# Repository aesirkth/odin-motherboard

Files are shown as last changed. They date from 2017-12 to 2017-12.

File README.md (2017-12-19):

# ÆSIR - Odin Motherboard
Odin Motherboard KiCad Design Files

This repository contains the motherboard KiCad design files for the ÆSIR Odin hybrid rocket.
Its main purpose is to house the on-board computer, a Teensy v3.6, and the breakouts to all external components in the rocket. These include: GPS, Go Pro, telemetry, servo, video/camera transmission, accelerometer, umbilical cord, and a safety pin. Use the reference_breakout.txt file to see where each output goes to. 

aesir.lib contains the schematic symbols for the BMP180, MPU-9250, and the motherboard plate (68 mm diameter)

AESIR.pretty contains the footprints for the BMP180, MPU-9250, and the motherboard plate (68 mm diameter).

The Teensy v3.6 KiCad component is required.
Download the schematic symbols and footprints from: 
https://github.com/XenGi/teensy_library

Watch our progress at http://aesir.se/!

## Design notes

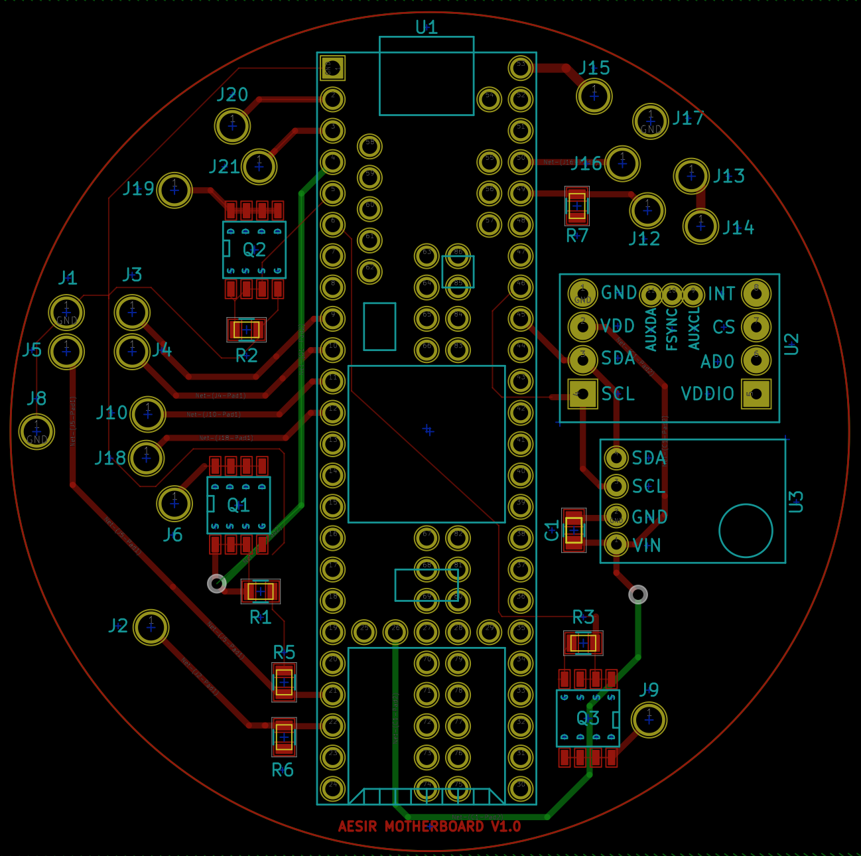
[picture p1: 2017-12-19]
AESIR_MB_FOOTPRINT.png

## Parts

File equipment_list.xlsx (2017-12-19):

No. | Description | Code | Web-link | Pcs. | Price/pcs. | VAT (if) | Price (SEK) | Description in OF | Notes
1 | RFD868+ Modem Bundle | BUNDLE-RFD868+ | http://store.rfdesign.com.au/rfd868-modem-bundle/ | 1 | 1550 | 387.5 | 1937.5 | Telemetry unit
2 | RF Extension Cable - RPSMA(M)-RPSMA(F) 15cm | CABLE-RPSMA-EXT-15cm | http://store.rfdesign.com.au/rf-extension-cable-rpsma-m-rpsma-f-15cm/ | 2 | 45 | 22.5 | 112.5
3 | RF Extension Cable - RPSMA(M)-RPSMA(F) 50cm | CABLE-RPSMA-EXT-50cm | http://store.rfdesign.com.au/rf-extension-cable-rpsma-m-rpsma-f-50cm/ | 2 | 40 | 20 | 100
4 | Transport for Modems & Accs. |  |  | 1 | 200 | 50 | 350
5 | RMRC - 1.3GHz 1000mW Transmitter | V2-1000MW1300MHZTX-INTL | https://www.readymaderc.com/store/index.php?main_page=product_info&cPath=11_30_38&products_id=921 | 1 | 800 | 200 | 1000 | Video unit
6 | RMRC - 900MHz-1.3Ghz Receiver w/1258 | V3-900MHZ-1.3GHZRX | https://www.readymaderc.com/store/index.php?main_page=product_info&cPath=11_34_44&products_id=912 | 1 | 490 | 122.5 | 612.5
7 | VAS - 1.3GHz BiQuad Antenna | BQ-1280 | https://www.readymaderc.com/store/index.php?main_page=product_info&cPath=11_45_52_99&products_id=378 | 1 | 625 | 156.25 | 781.25
8 | 30cm (1ft) SMA Female to SMA Male RG316 Extension | SMAMF30CM | https://www.readymaderc.com/store/index.php?main_page=product_info&cPath=11_45_58&products_id=250 | 1 | 70 | 17.5 | 87.5
9 | 15cm SMA Female to SMA Male RG316 Extension | SMAMF15CM | https://www.readymaderc.com/store/index.php?main_page=product_info&cPath=11_45_58&products_id=3726 | 2 | 35 | 17.5 | 87.5
10 | Shipping for Video items |  |  | 1 | 200 | 50 | 250
11 | Data Acquisition | DI-710-UL | https://www.dataq.com/products/di-710/di-710-ul.html | 1 | 4420 | 1105 | 5525 | DAQ
12 | Shipping for DAQ |  |  | 1 | 780 | 195 | 975
12 | GoPro Hero4 Black |  | http://www.elgiganten.se/product/foto-video/actionkamera/GOPROHER4BLK/gopro-hero-4-black-adventure-edition-actionkamera | 1 | 4000 | 0 | 4000 |  | need 4 black because it's the last one that has the plug to command the recording
 | Funding from the Opportunities Grant = |  | 16100 |  |  | Total | 15818.75
 |  |  |  |  |  | Total telem. | 2500
 | Contains equipment for both motherboard and daugterboard |  |  |  |  | Total video | 2818.75
 |  |  |  |  |  | Remaining | 281.25
 | Others
13 | Resistors |  | http://se.farnell.com/yageo-phycomp/rc0805fr-071kl/motst-tjockfilm-1k-1-0-125w-0805/dp/9237496 | 10 | 0.12 |  | 1.2 | Farnell
14 | N type mosfet |  | http://se.farnell.com/vishay/si4840bdy-t1-e3/mosfet-n-so-8/dp/1684057 | 8 | 11.06 |  | 88.48
15 | Diodes |  | http://se.farnell.com/bourns/cd214b-r3600/diode-chip-600v-3a-do-214aa/dp/2311234 | 6 | 3.72 |  | 22.32
16 | Supercap |  | http://se.farnell.com/vishay/mal219613473e3/cap-double-47000uf-6-3v-rad/dp/1695337 | 1 | 53 |  | 53
17 | Shipping for Farnell |  |  | 1 | 200 |  | 200
18 | Step down reg |  | https://www.pololu.com/product/2852 | 3 | 105 | 78.75 | 393.75 | Pololu
19 | Step up reg |  | https://www.pololu.com/product/2117 | 2 | 35 | 17.5 | 87.5
20 | Arduino mini pro |  | https://www.sparkfun.com/products/11113 | 3 | 89 | 66.75 | 333.75 | Sparkfun
21 | Arduino Stackable Header Kit |  | https://www.sparkfun.com/products/11417 | 3 | 14 | 10.5 | 52.5
22 | SparkFun microSD Breakout board |  | https://www.sparkfun.com/products/13743 | 1 | 45 | 11.25 | 56.25
23 | miscellaneous |  |  | 0 |  | 0 | 200
24 | SparkFun IMU Breakout - MPU-9250 |  | https://www.sparkfun.com/products/13762 | 1 | 132 | 33 | 165
25 | SparkFun Logic Level Converter |  | https://www.sparkfun.com/products/12009 | 2 | 27 | 13.5 | 67.5
26 | Micro SD card for GoPro |  |  | 1 |  |  |  |  | 32gb - class enough for 2.7k 60fps
27 | Micro SD card for data storage |  |  | 1 |  |  |  |  | not bigger than 4gb
26 | Force cell sensor | MSP6954-ND | http://www.digikey.com/products/en/sensors-transducers/force-sensors/531?k=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 | 1 | 1062 | 265.5 | 1327.5 | Digikey
27 | Shippind for force cell |  |  | 1 | 70 | 17.5 | 87.5
 |  |  |  |  |  | Total | 3136.25

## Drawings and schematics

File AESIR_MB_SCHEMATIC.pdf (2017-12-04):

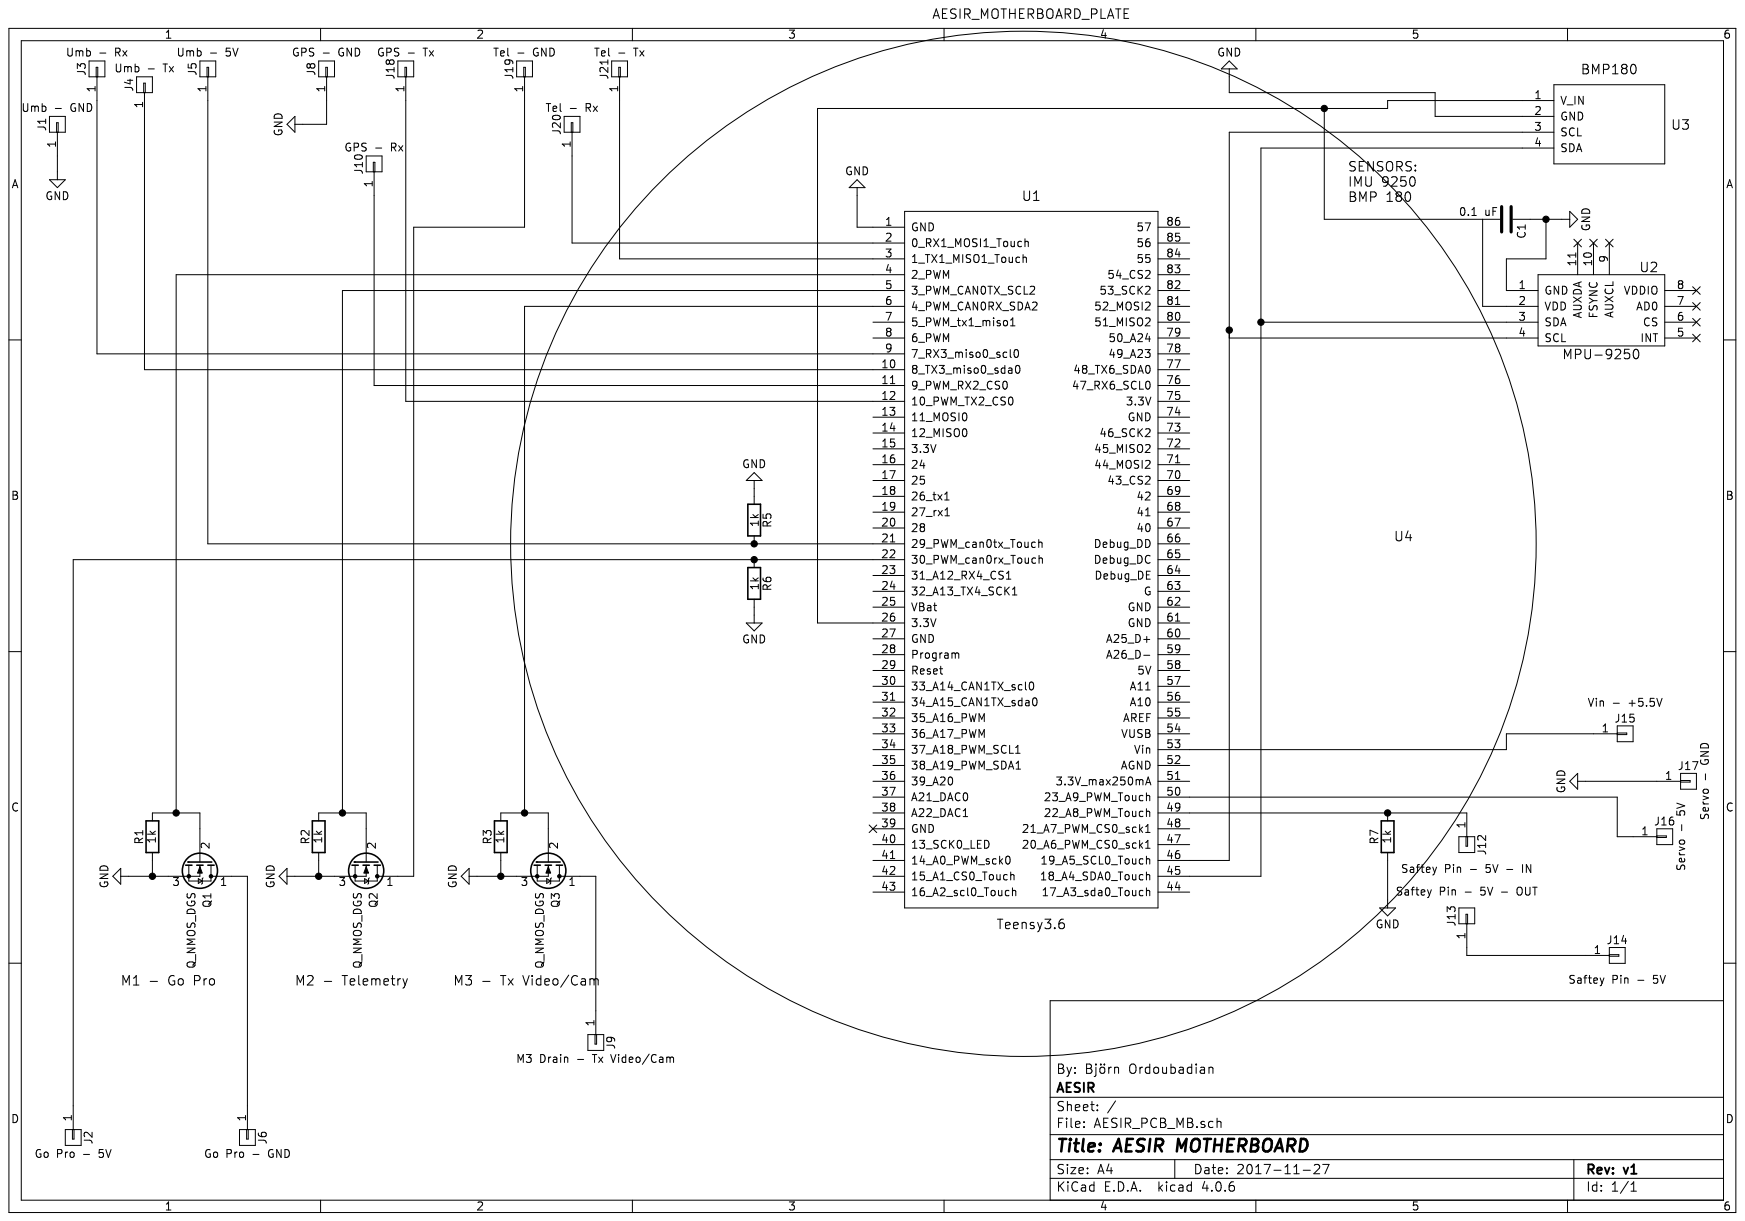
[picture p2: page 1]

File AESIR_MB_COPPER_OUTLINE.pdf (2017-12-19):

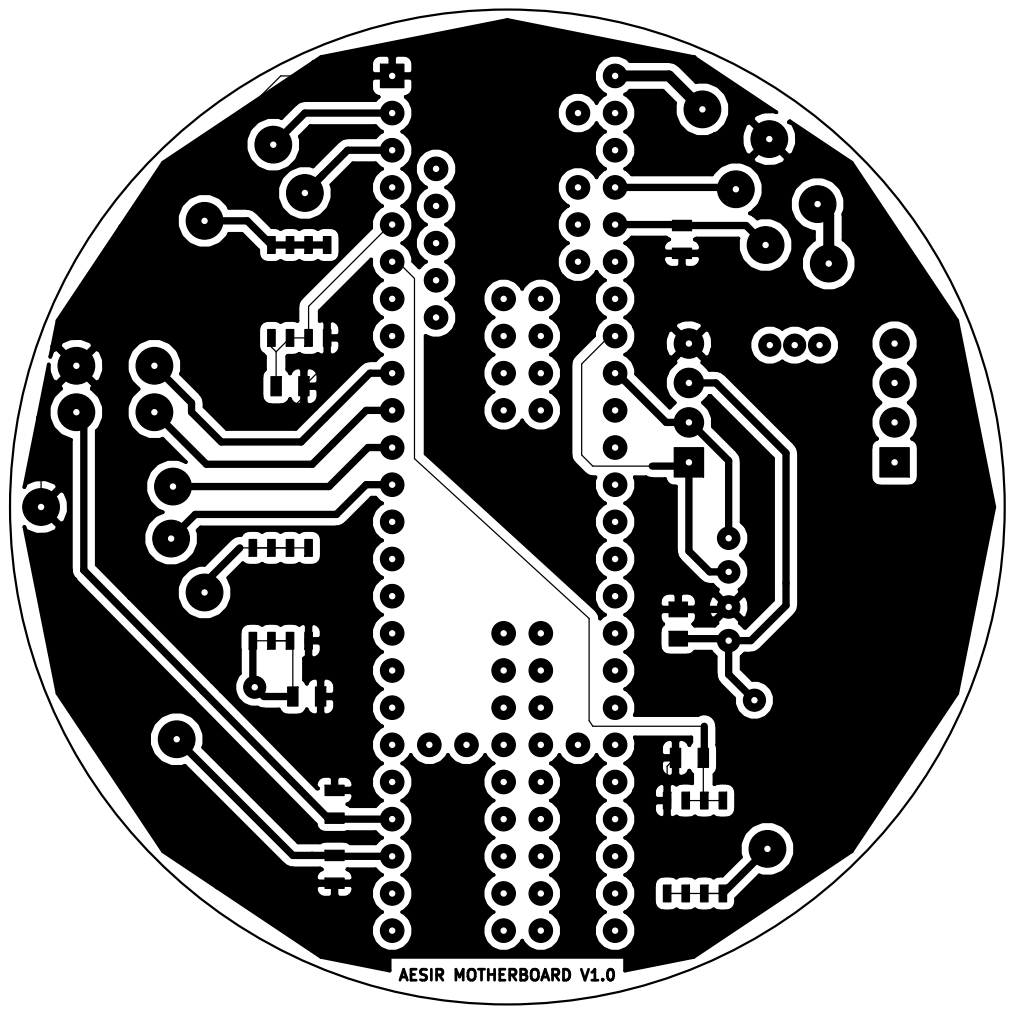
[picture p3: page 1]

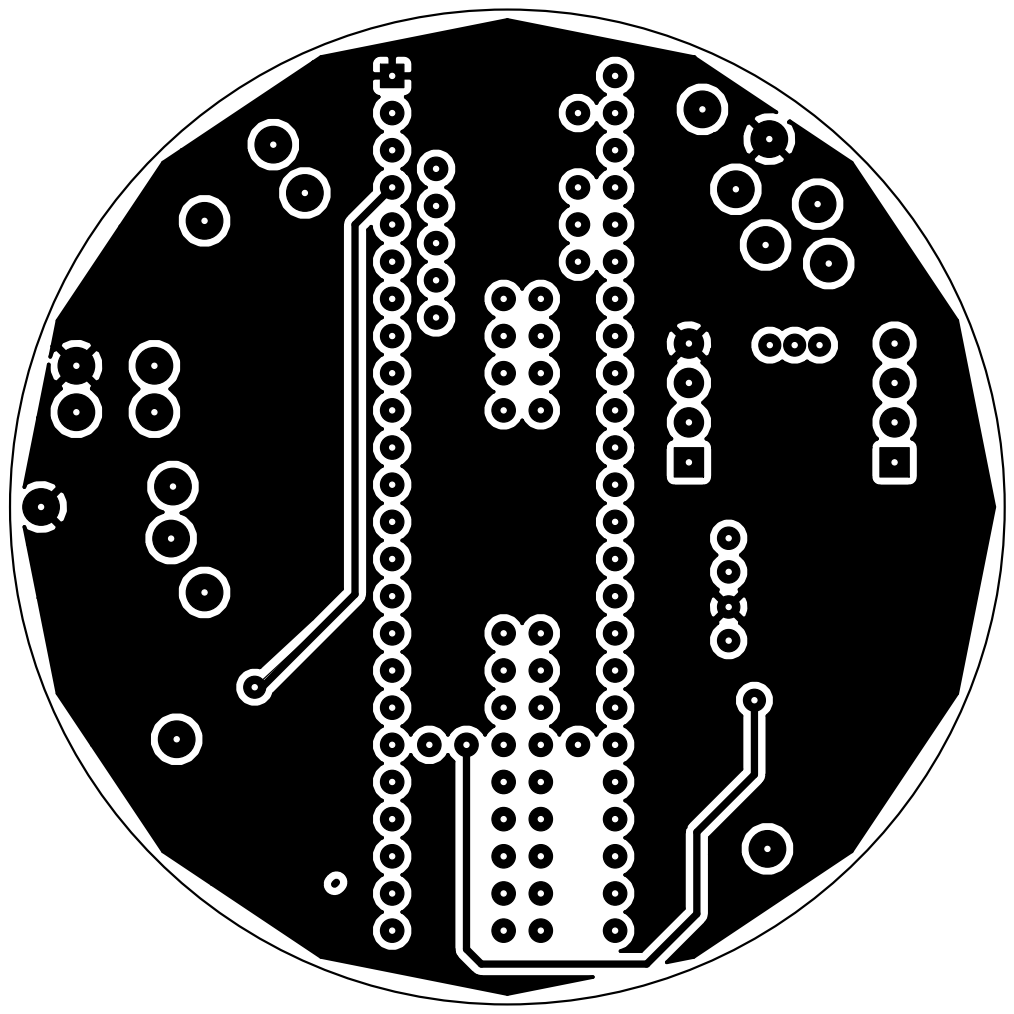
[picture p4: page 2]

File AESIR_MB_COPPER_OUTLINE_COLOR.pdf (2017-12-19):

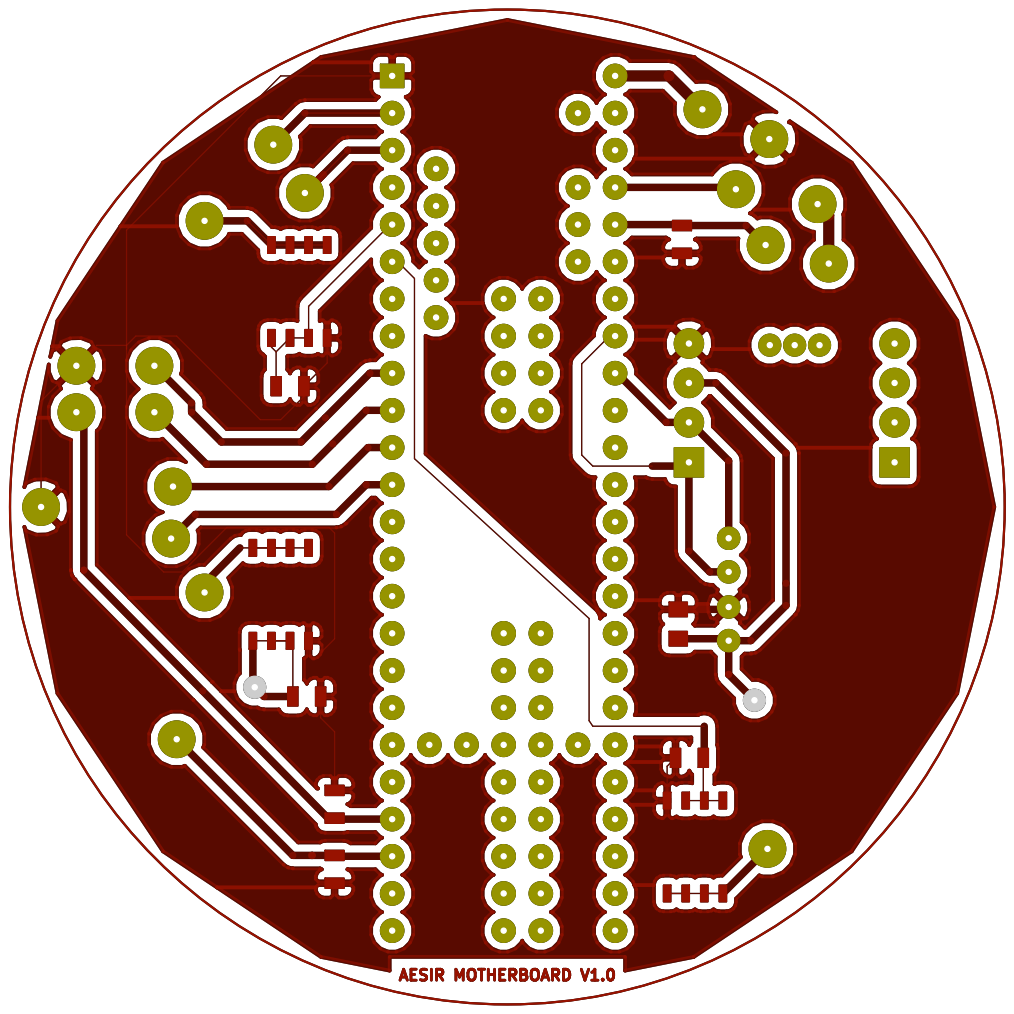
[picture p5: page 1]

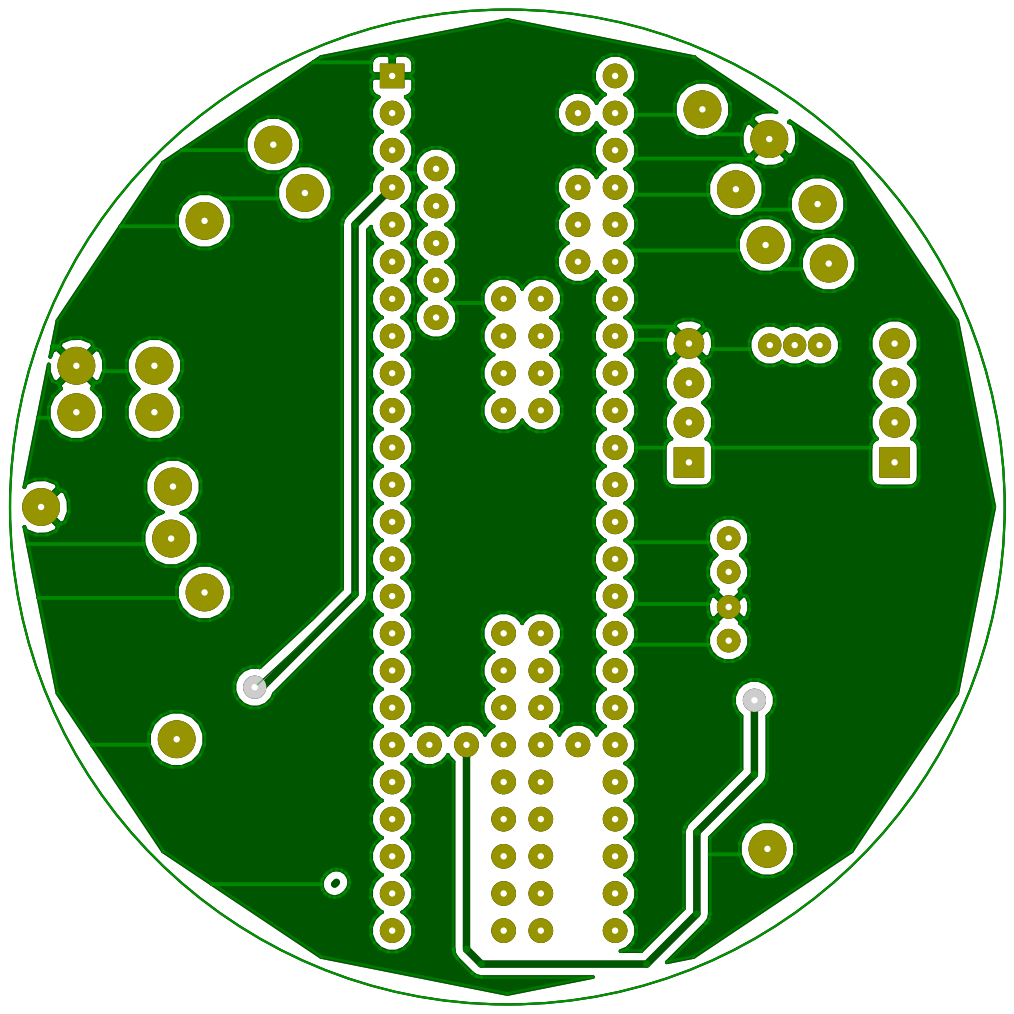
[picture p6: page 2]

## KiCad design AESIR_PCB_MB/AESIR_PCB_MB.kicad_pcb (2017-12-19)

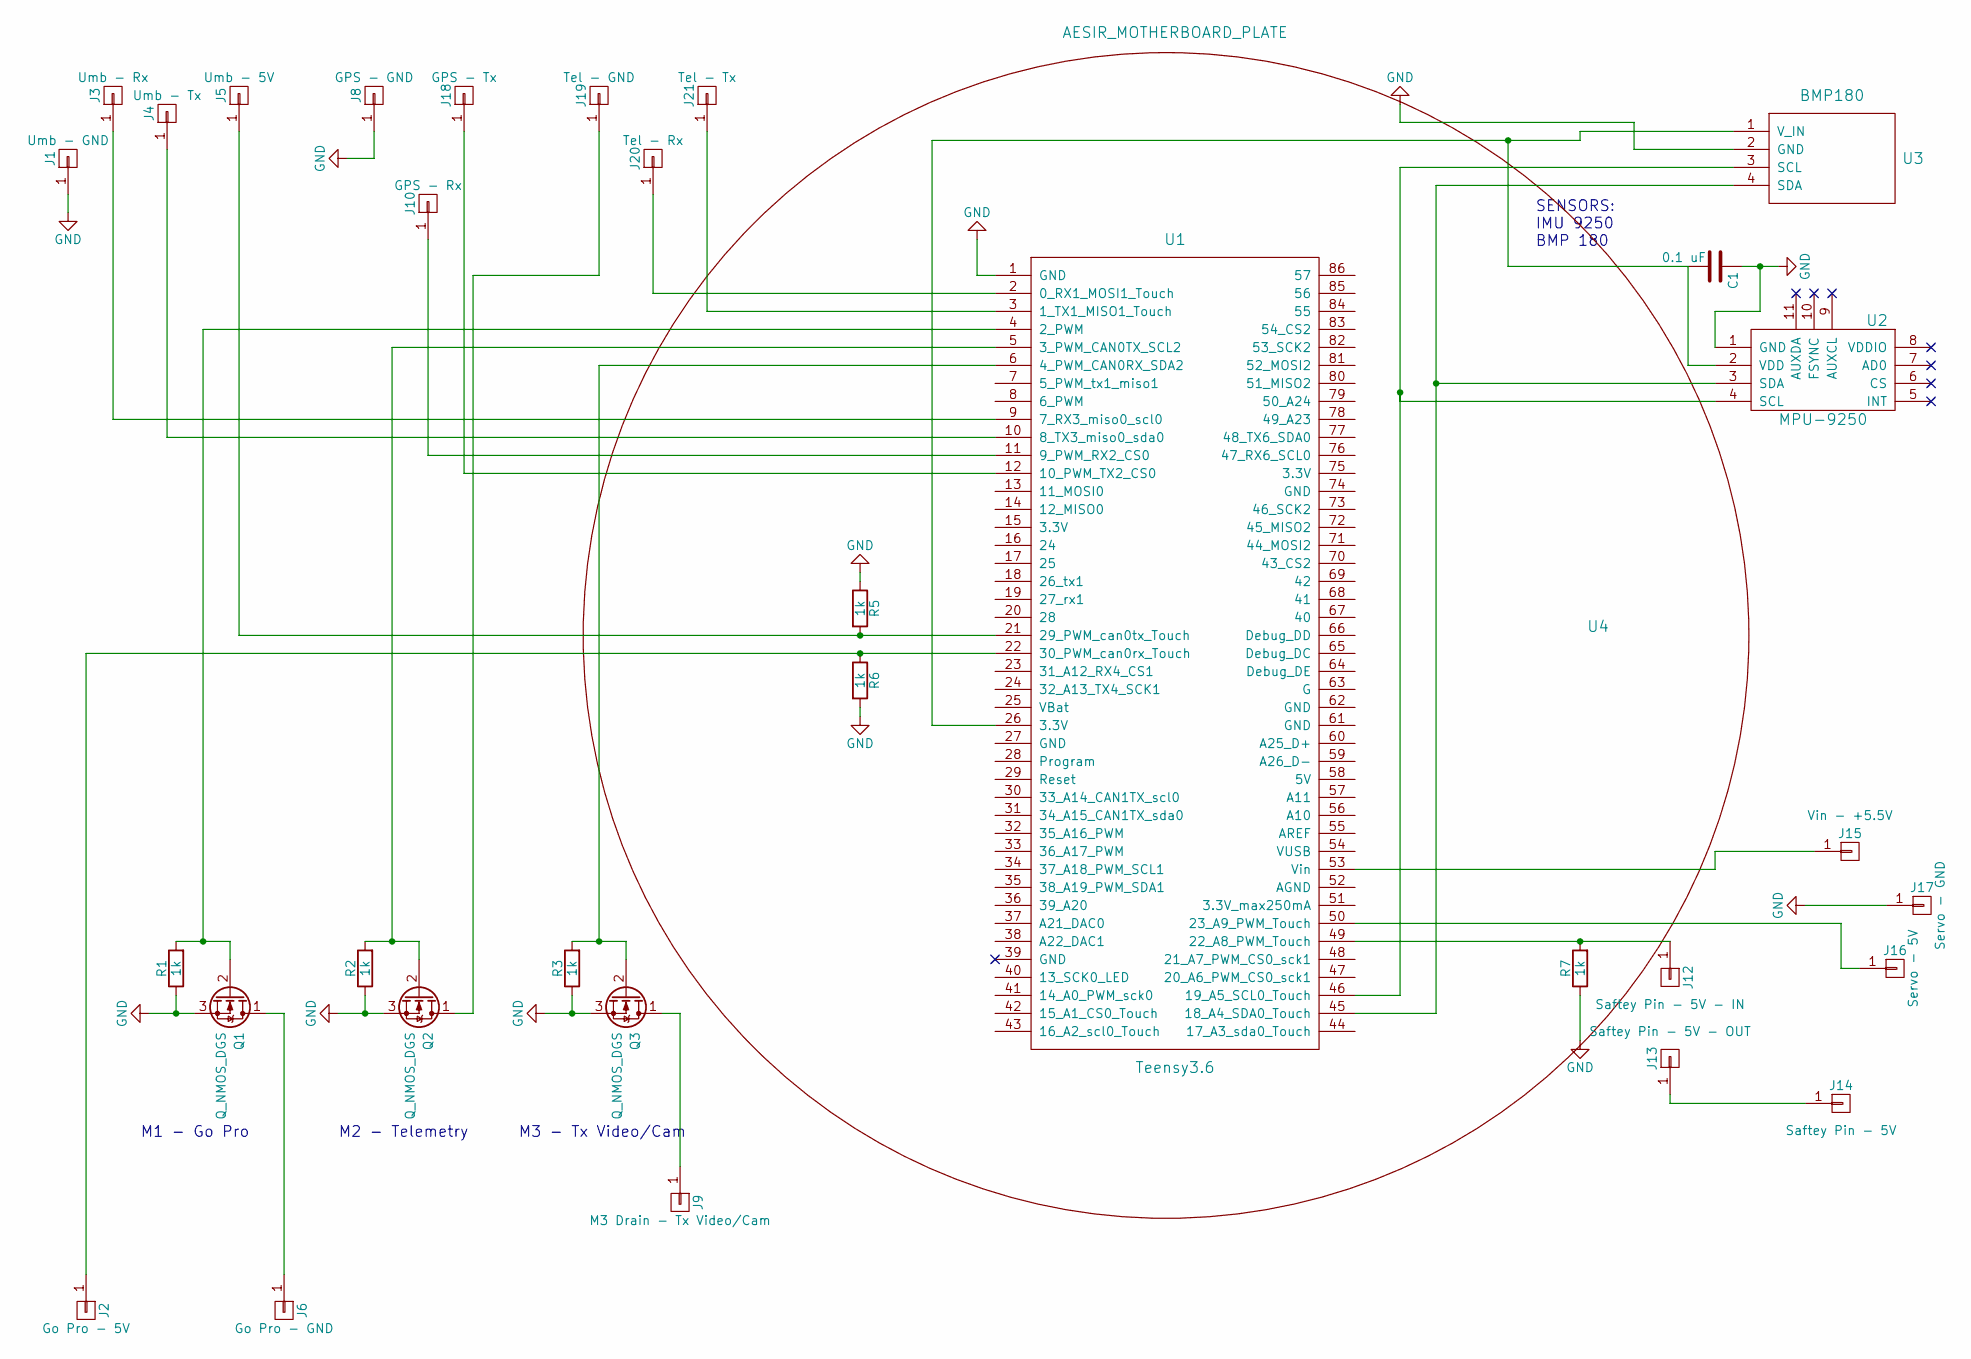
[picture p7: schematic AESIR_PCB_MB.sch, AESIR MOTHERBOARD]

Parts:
C1: 0.1 uF; C_0805
J1: Umb - GND; SolderWirePad_single_2mmDrill
J2: Go Pro - 5V; SolderWirePad_single_2mmDrill
J3: Umb - Rx; SolderWirePad_single_2mmDrill
J4: Umb - Tx; SolderWirePad_single_2mmDrill
J5: Umb - 5V; SolderWirePad_single_2mmDrill
J6: Go Pro - GND; SolderWirePad_single_2mmDrill
J8: GPS - GND; SolderWirePad_single_2mmDrill
J9: M3 Drain - Tx Video/Cam; SolderWirePad_single_2mmDrill
J10: GPS - Rx; SolderWirePad_single_2mmDrill
J12: Saftey Pin - 5V - IN; SolderWirePad_single_2mmDrill
J13: Saftey Pin - 5V - OUT; SolderWirePad_single_2mmDrill
J14: Saftey Pin - 5V; SolderWirePad_single_2mmDrill
J15: Vin - +5.5V; SolderWirePad_single_2mmDrill
J16: Servo - 5V; SolderWirePad_single_2mmDrill
J17: Servo - GND; SolderWirePad_single_2mmDrill
J18: GPS - Tx; SolderWirePad_single_2mmDrill
J19: Tel - GND; SolderWirePad_single_2mmDrill
J20: Tel - Rx; SolderWirePad_single_2mmDrill
J21: Tel - Tx; SolderWirePad_single_2mmDrill
Q1, Q2, Q3: Q_NMOS_DGS; SOIC-8-N-AESIR
R1, R2, R3, R5, R6, R7: 1k; R_0805
U1: Teensy3.6; Teensy35_36
U2: MPU-9250
U3: BMP180
U4: AESIR_MOTHERBOARD_PLATE; AESIR_MB_OUTLINE_68mm

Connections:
GND: C1.1, J1.1, J8.1, J17.1, Q1.3 (S), Q2.3 (S), Q3.3 (S), R1.1, R2.1, R3.1, R5.1, R6.2, R7.1, U1.1 (GND), U2.1 (GND), U3.2 (GND)
unnamed: C1.2, U1.26 (3.3V), U2.2 (VDD), U3.1 (V_IN)
unnamed: J2.1, R6.1, U1.22 (30_PWM_can0rx_Touch)
unnamed: J3.1, U1.9 (7_RX3_miso0_scl0)
unnamed: J4.1, U1.10 (8_TX3_miso0_sda0)
unnamed: J5.1, R5.2, U1.21 (29_PWM_can0tx_Touch)
unnamed: J6.1, Q1.1 (D)
unnamed: J9.1, Q3.1 (D)
unnamed: J10.1, U1.11 (9_PWM_RX2_CS0)
unnamed: J12.1, R7.2, U1.49 (22_A8_PWM_Touch)
unnamed: J13.1, J14.1
unnamed: J15.1, U1.53 (Vin)
unnamed: J16.1, U1.50 (23_A9_PWM_Touch)
unnamed: J18.1, U1.12 (10_PWM_TX2_CS0)
unnamed: J19.1, Q2.1 (D)
unnamed: J20.1, U1.2 (0_RX1_MOSI1_Touch)
unnamed: J21.1, U1.3 (1_TX1_MISO1_Touch)
unnamed: Q1.2 (G), R1.2, U1.4 (2_PWM)
unnamed: Q2.2 (G), R2.2, U1.5 (3_PWM_CAN0TX_SCL2)
unnamed: Q3.2 (G), R3.2, U1.6 (4_PWM_CAN0RX_SDA2)
unnamed: U1.45 (18_A4_SDA0_Touch), U2.3 (SDA), U3.4 (SDA)
unnamed: U1.46 (19_A5_SCL0_Touch), U2.4 (SCL), U3.3 (SCL)

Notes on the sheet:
M2 - Telemetry
M1 - Go Pro
SENSORS: IMU 9250 BMP 180
M3 - Tx Video/Cam

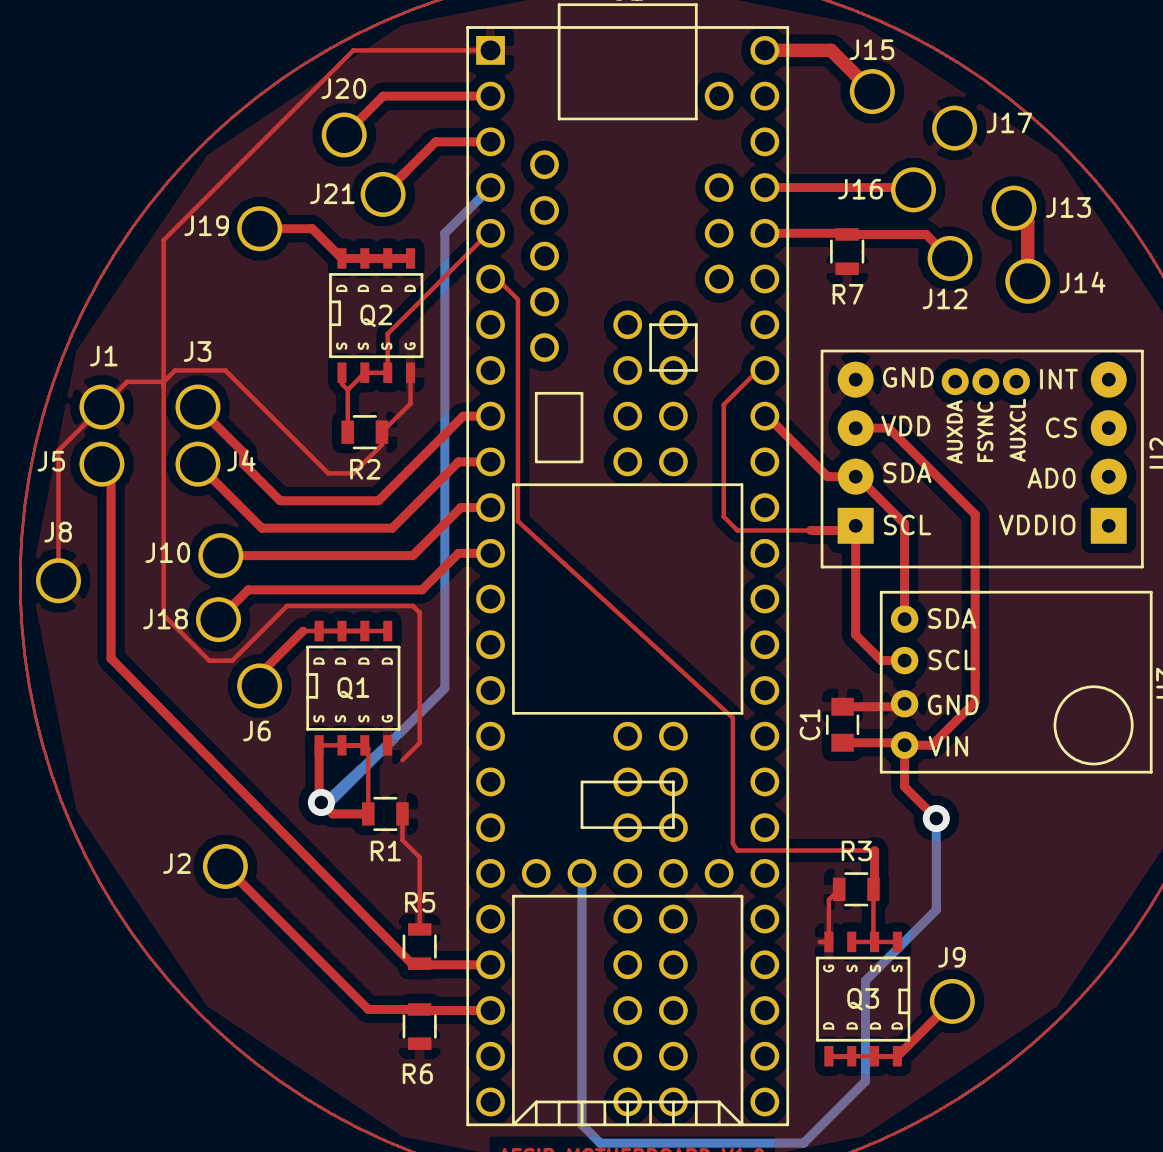
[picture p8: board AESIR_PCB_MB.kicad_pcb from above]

Board: 2 copper layers, 33 parts (0 on the bottom side), 22 nets.

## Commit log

2017-12-04 added motherboard files
    [AESIR_PCB_MB 3.sch, AESIR_PCB_MB.kicad_pcb, AESIR_PCB_MB.sch]
2017-12-19 finalized motherboard design, added library files
    [AESIR_PCB_MB 3.sch, AESIR_PCB_MB.kicad_pcb, AESIR_PCB_MB.sch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]
2017-12-19 minor update on board + added more documentation
    [AESIR_PCB_MB.kicad_pcb]
